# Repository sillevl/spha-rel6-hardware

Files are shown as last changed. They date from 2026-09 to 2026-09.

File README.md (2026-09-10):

# Six-channel relay module

SPHA six-channel relay/light-output module.

## Design files

- `relay-module-light.kicad_pro` — KiCad project
- `relay-module-light.kicad_sch` — top-level schematic
- `relay-module-light.kicad_pcb` — PCB layout
- Additional `.kicad_sch` files — hierarchical schematic sheets
- `models/` — project-specific 3D and mechanical models

## Working with the project

Open the `.kicad_pro` file in KiCad. The design includes files originating from an older KiCad workflow; review schematic links, footprints, design rules, zones, and manufacturing outputs after any conversion or upgrade.

KiCad source files and project-specific libraries are the source of truth. Generated BOM, Gerber, assembly, and fabrication-house outputs are excluded from the repository; regenerate and verify them before manufacturing.

## Repository notes

Temporary KiCad state, locks, autosaves, and backup directories are excluded by `.gitignore`. Board revision, tested KiCad version, manufacturing revision, and hardware/firmware compatibility still need to be recorded when provenance is confirmed.

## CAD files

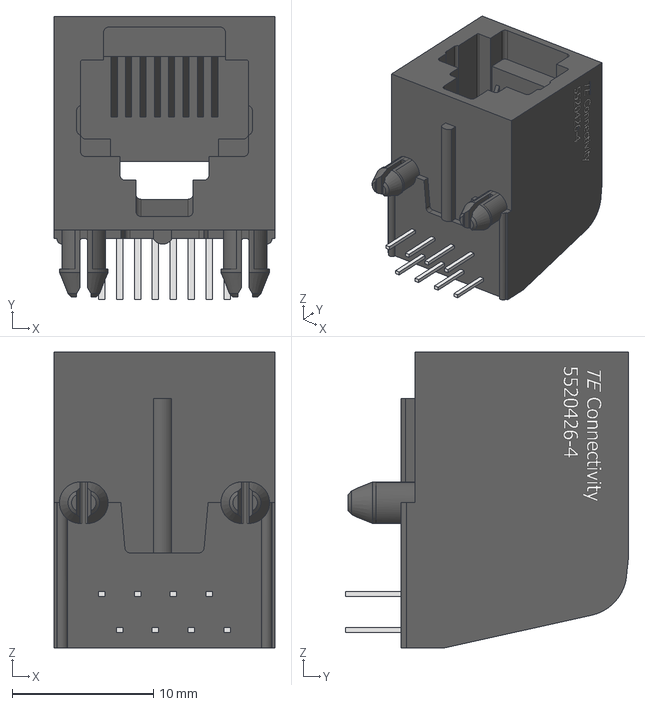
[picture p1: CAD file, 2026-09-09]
models/TE_Connectivity_-_5520426-4.step
15.6 x 20.1 x 21.0 mm
c-5520426-4-a-3d
sdfsdfsdfsdfsdfsdfsdf x 8

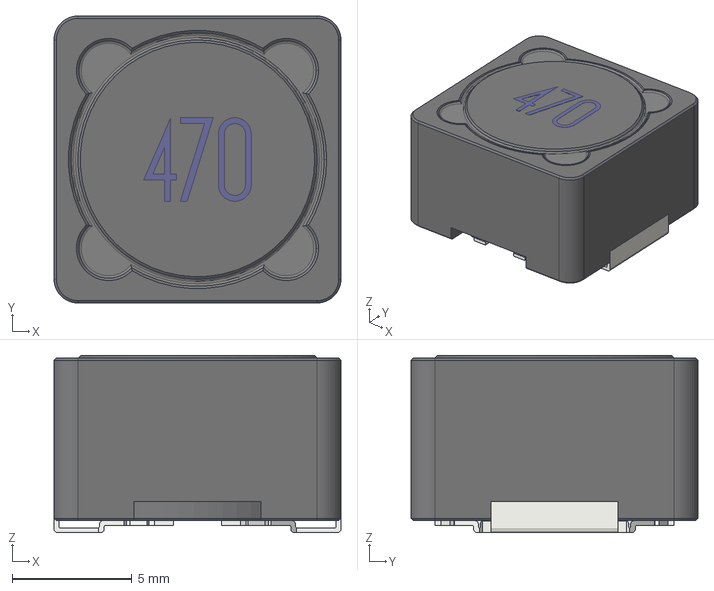
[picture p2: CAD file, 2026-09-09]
models/CDRH127_470M.step
12.0 x 12.0 x 7.41 mm

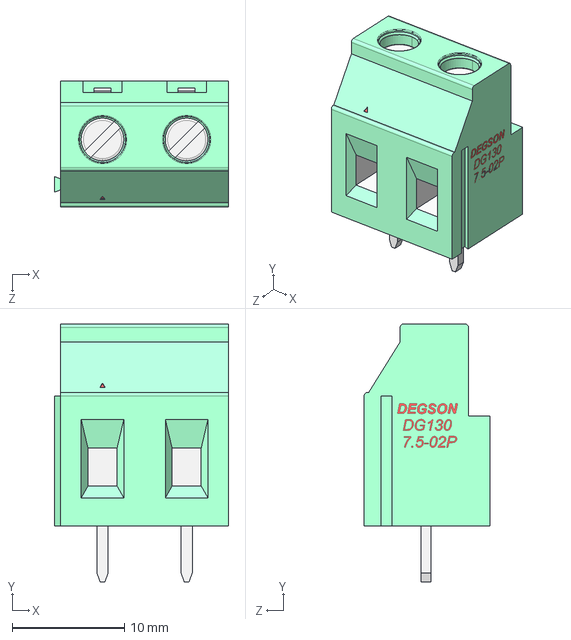
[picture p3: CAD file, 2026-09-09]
models/DG130-7.5-02P-14-00AH.STEP
15.6 x 23.0 x 11.2 mm

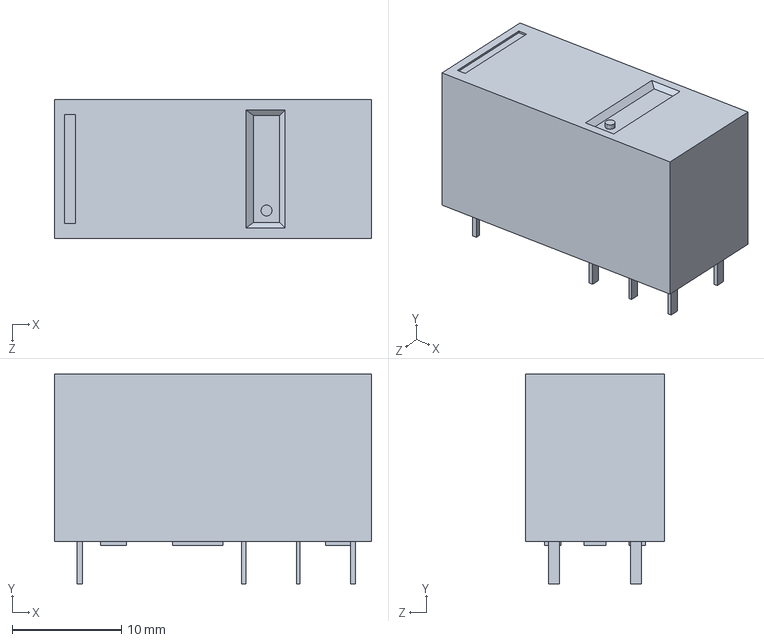
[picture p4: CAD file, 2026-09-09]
models/G5RL_1_E_HR.step
29.0 x 19.2 x 12.7 mm

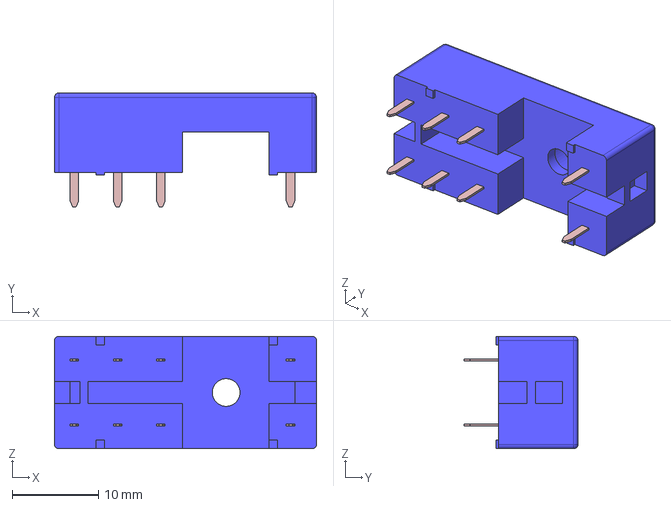
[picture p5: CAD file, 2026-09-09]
models/95152.stp
30.3 x 13.2 x 13.0 mm

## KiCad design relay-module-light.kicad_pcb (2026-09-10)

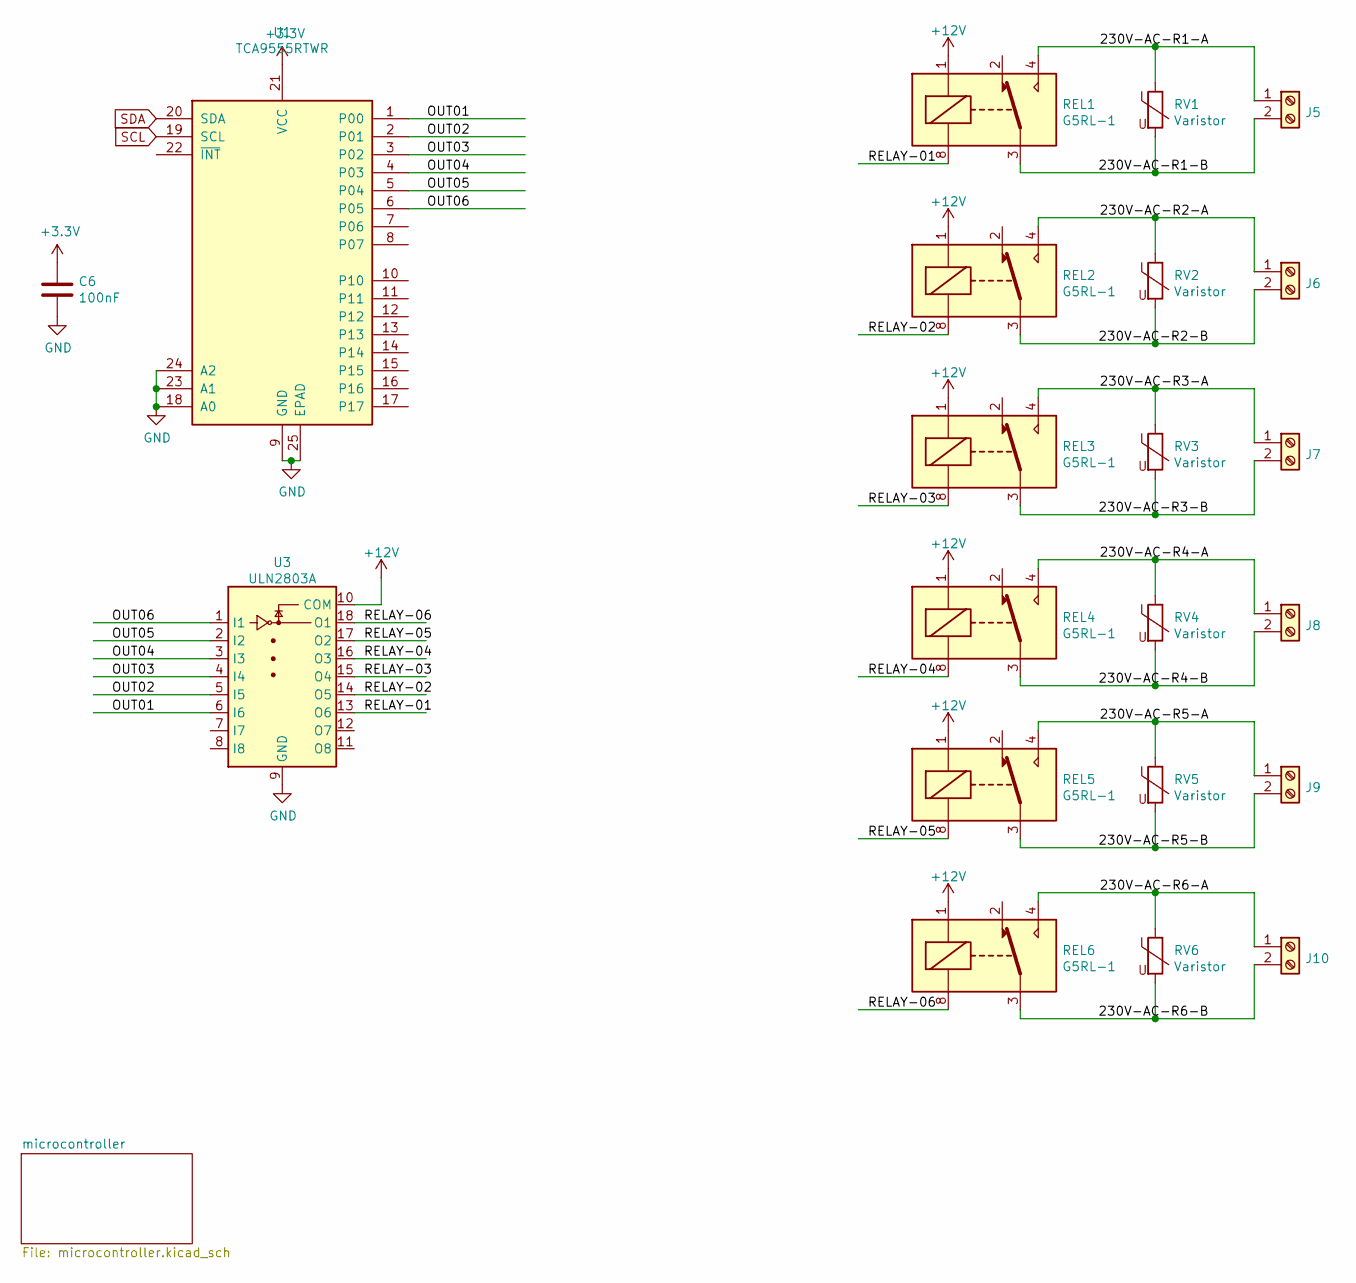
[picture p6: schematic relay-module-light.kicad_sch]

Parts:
C6: 100nF; C_0603_1608Metric_Pad1.05x0.95mm_HandSolder
J5, J6, J7, J8, J9, J10: Screw_Terminal_01x02; TerminalBlock_MetzConnect_Type175_RT02702HBLC_1x02_P7.50mm_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
REL1, REL2, REL3, REL4, REL5, REL6: G5RL-1; Relay_DPDT_Omron_G2RL
RV1, RV2, RV3, RV4, RV5, RV6: Varistor; RV_Disc_D7mm_W4mm_P5mm
U1: TCA9555RTWR; WQFN-24-1EP_4x4mm_P0.5mm_EP2.45x2.45mm
U3: ULN2803A; SOP-18_7x12.5mm_P1.27mm

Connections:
+3V3: C6.1, U1.21 (VCC); also elsewhere on the board
+12V: REL1.1, REL2.1, REL3.1, REL4.1, REL5.1, REL6.1, U3.10 (COM); also elsewhere on the board
/230V-AC-R1-A: J5.1, REL1.4, REL1.5, RV1.1
/230V-AC-R1-B: J5.2, REL1.3, REL1.6, RV1.2
/230V-AC-R2-A: J6.1, REL2.4, REL2.5, RV2.1
/230V-AC-R2-B: J6.2, REL2.3, REL2.6, RV2.2
/230V-AC-R3-A: J7.1, REL3.4, REL3.5, RV3.1
/230V-AC-R3-B: J7.2, REL3.3, REL3.6, RV3.2
/230V-AC-R4-A: J8.1, REL4.4, REL4.5, RV4.1
/230V-AC-R4-B: J8.2, REL4.3, REL4.6, RV4.2
/230V-AC-R5-A: J9.1, REL5.4, REL5.5, RV5.1
/230V-AC-R5-B: J9.2, REL5.3, REL5.6, RV5.2
/230V-AC-R6-A: J10.1, REL6.4, REL6.5, RV6.1
/230V-AC-R6-B: J10.2, REL6.3, REL6.6, RV6.2
/OUT01: U1.1 (P00), U3.6 (I6)
/OUT02: U1.2 (P01), U3.5 (I5)
/OUT03: U1.3 (P02), U3.4 (I4)
/OUT04: U1.4 (P03), U3.3 (I3)
/OUT05: U1.5 (P04), U3.2 (I2)
/OUT06: U1.6 (P05), U3.1 (I1)
/RELAY-01: REL1.8, U3.13 (O6)
/RELAY-02: REL2.8, U3.14 (O5)
/RELAY-03: REL3.8, U3.15 (O4)
/RELAY-04: REL4.8, U3.16 (O3)
/RELAY-05: REL5.8, U3.17 (O2)
/RELAY-06: REL6.8, U3.18 (O1)
unnamed: REL1.2, REL1.7
unnamed: REL2.2, REL2.7
unnamed: REL3.2, REL3.7
unnamed: REL4.2, REL4.7
unnamed: REL5.2, REL5.7
unnamed: REL6.2, REL6.7
SCL: U1.19 (SCL); also elsewhere on the board
SDA: U1.20 (SDA); also elsewhere on the board

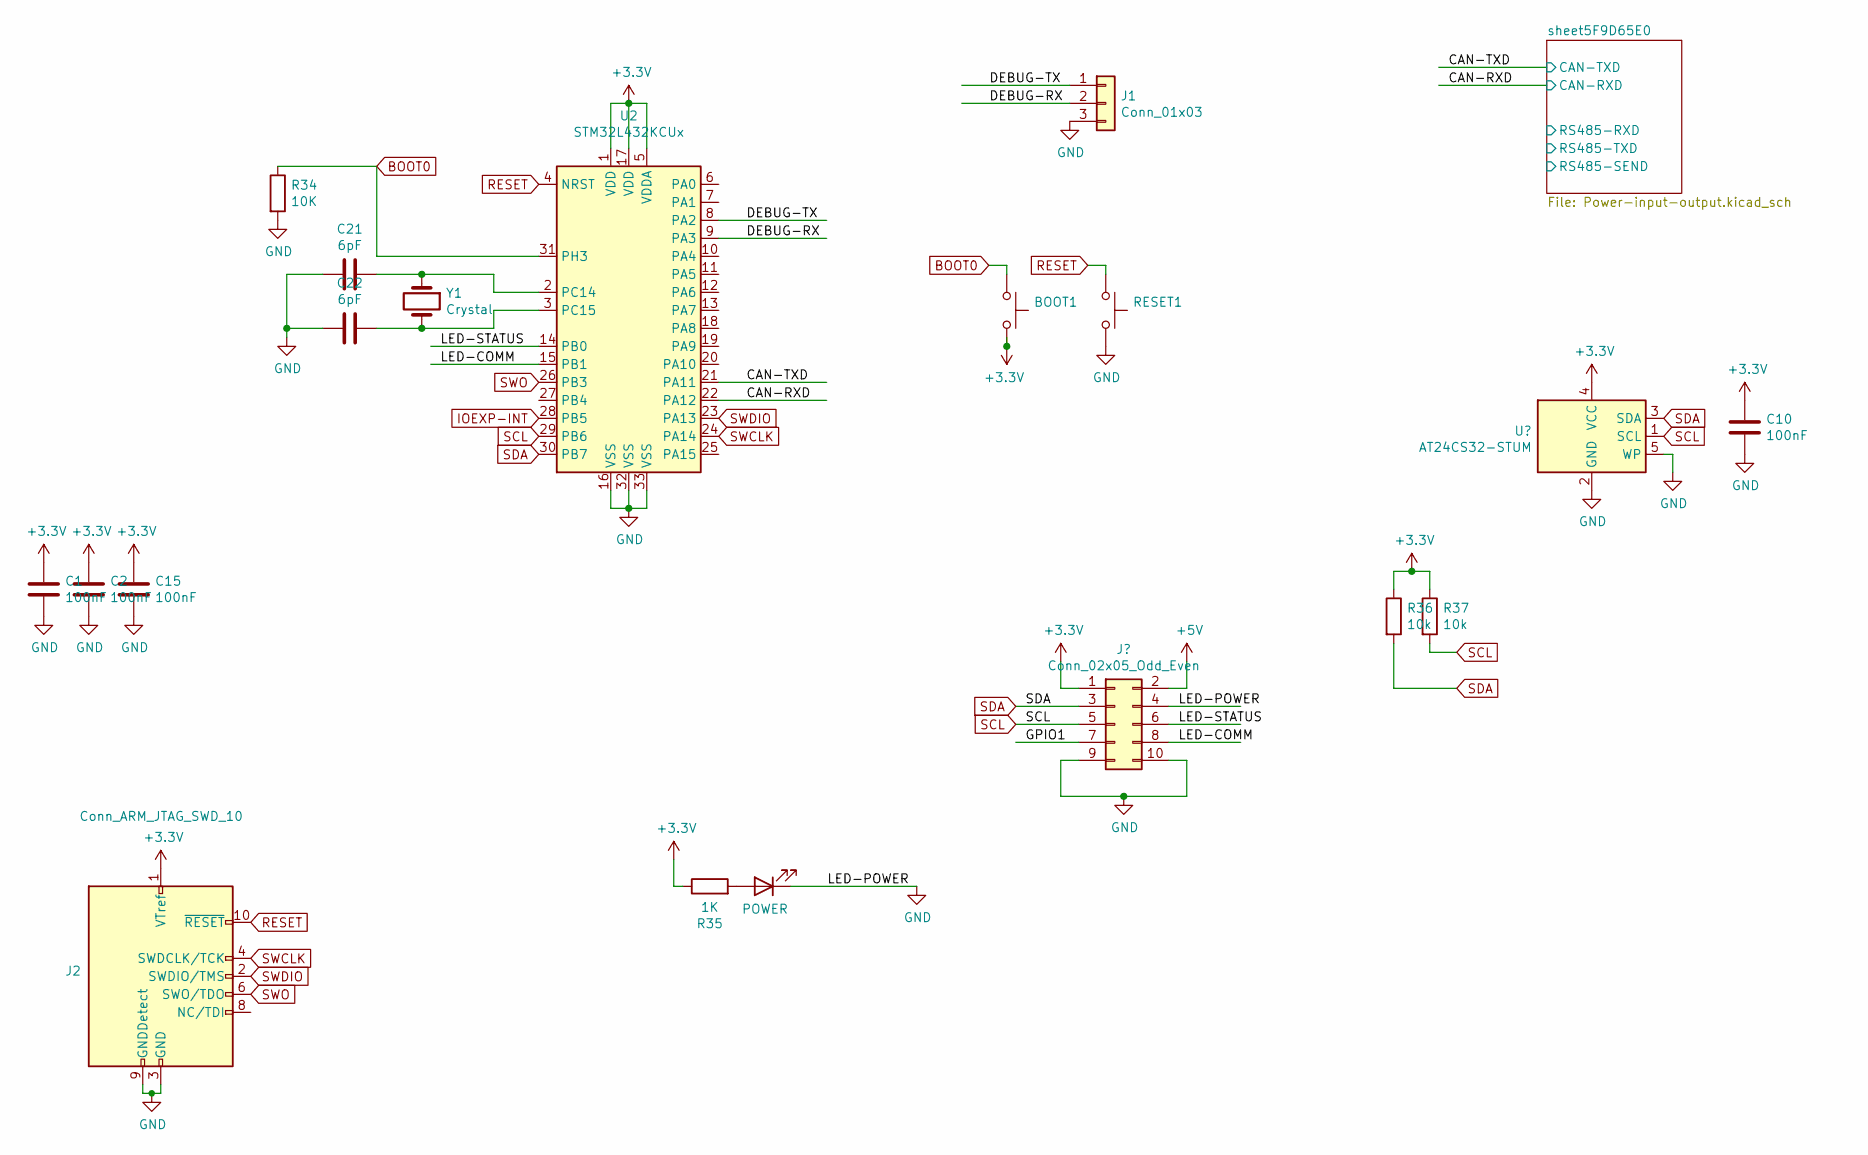
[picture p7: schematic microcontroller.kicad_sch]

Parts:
BOOT1: BOOT0; SW_SPST_B3U-1000P
C1, C2, C10, C15: 100nF; C_0603_1608Metric_Pad1.05x0.95mm_HandSolder
C21, C22: 6pF; C_0603_1608Metric_Pad1.05x0.95mm_HandSolder
J1: Conn_01x03; PinHeader_1x03_P2.54mm_Vertical
J2: Conn_ARM_JTAG_SWD_10; PinHeader_2x05_P1.27mm_Vertical_SMD
LED1: POWER; LED_0603_1608Metric_Pad1.05x0.95mm_HandSolder
R34: 10K; C_0603_1608Metric_Pad1.05x0.95mm_HandSolder
R35: 1K; C_0603_1608Metric_Pad1.05x0.95mm_HandSolder
R36, R37: 10k; C_0603_1608Metric_Pad1.05x0.95mm_HandSolder
RESET1: RESET; SW_SPST_B3U-1000P
U2: STM32L432KCUx; QFN-32-1EP_5x5mm_P0.5mm_EP3.45x3.45mm
Y1: Crystal; Crystal_SMD_MicroCrystal_CC7V-T1A-2Pin_3.2x1.5mm

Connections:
+3V3: BOOT1.2, C1.1, C2.1, C10.1, C15.1, J2.1 (VTref), R35.1, R36.1, R37.1, U2.1 (VDD), U2.5 (VDDA), U2.17 (VDD); also elsewhere on the board
/microcontroller/CAN-RXD: U2.22 (PA12); also elsewhere on the board
/microcontroller/CAN-TXD: U2.21 (PA11); also elsewhere on the board
/microcontroller/DEBUG-RX: J1.2, U2.9 (PA3)
/microcontroller/DEBUG-TX: J1.1, U2.8 (PA2)
/microcontroller/LED-COMM: U2.15 (PB1); also elsewhere on the board
/microcontroller/LED-STATUS: U2.14 (PB0); also elsewhere on the board
BOOT0: BOOT1.1, R34.1, U2.31 (PH3)
unnamed: C21.1, U2.2 (PC14), Y1.1
unnamed: C22.1, U2.3 (PC15), Y1.2
unnamed: LED1.2 (A), R35.2
RESET: J2.10 (~RESET~), RESET1.1, U2.4 (NRST)
SCL: R37.2, U2.29 (PB6); also elsewhere on the board
SDA: R36.2, U2.30 (PB7); also elsewhere on the board
SWCLK: J2.4 (SWDCLK/TCK), U2.24 (PA14)
SWDIO: J2.2 (SWDIO/TMS), U2.23 (PA13)
SWO: J2.6 (SWO/TDO), U2.26 (PB3)

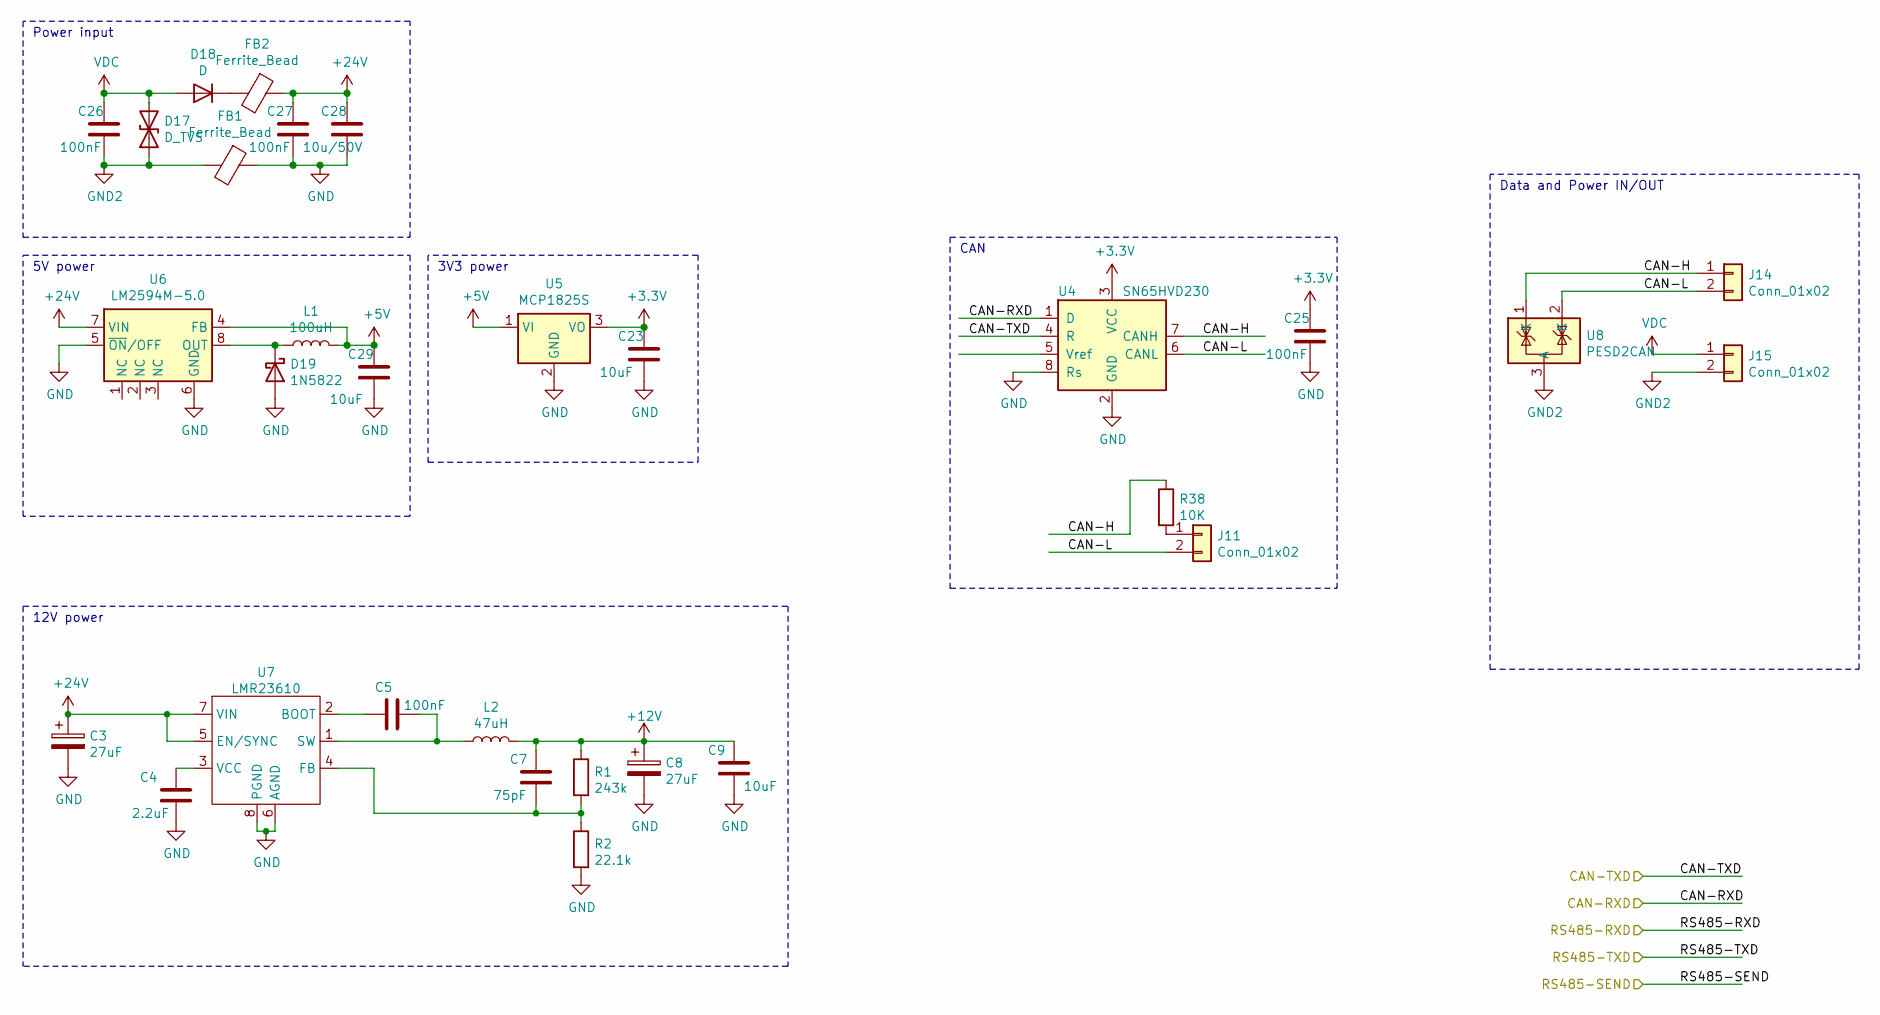
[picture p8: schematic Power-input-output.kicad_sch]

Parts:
C3, C8: 27uF; CP_Elec_6.3x5.7
C4: 2.2uF; C_0603_1608Metric
C5, C25, C26, C27: 100nF; C_0603_1608Metric
C7: 75pF; C_0603_1608Metric
C9, C23, C29: 10uF; C_1206_3216Metric
C28: 10u/50V; C_1206_3216Metric
D17: D_TVS; D_SMB
D18: D; D_SMA
D19: 1N5822; D_SOD-123
FB1, FB2: Ferrite_Bead; R_0603_1608Metric
J11: Conn_01x02; PinHeader_1x02_P2.54mm_Vertical
J14, J15: Conn_01x02; TerminalBlock_bornier-2_P5.08mm
L1: 100uH; L_Wuerth_WE-PD2-Typ-MS
L2: 47uH; L_12x12mm_H8mm
R1: 243k; R_0603_1608Metric
R2: 22.1k; R_0603_1608Metric
R38: 10K; R_0603_1608Metric
U4: SN65HVD230; SOIC-8_3.9x4.9mm_P1.27mm
U5: MCP1825S; SOT-223
U6: LM2594M-5.0; SOIC-8_3.9x4.9mm_P1.27mm
U7: LMR23610; HSOIC-8
U8: PESD2CAN; SOT-23

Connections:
+3V3: C23.1, C25.1, U4.3 (VCC), U5.3 (VO); also elsewhere on the board
+5V: C29.1, L1.2, U5.1 (VI), U6.4 (FB); also elsewhere on the board
+12V: C7.2, C8.1, C9.1, L2.2, R1.1; also elsewhere on the board
+24V: C3.1, C27.1, C28.1, FB2.1, U6.7 (VIN), U7.5 (EN/SYNC), U7.7 (VIN)
/microcontroller/CAN-RXD: U4.1 (D); also elsewhere on the board
/microcontroller/CAN-TXD: U4.4 (R); also elsewhere on the board
/microcontroller/sheet5F9D65E0/CAN-H: J14.1, R38.1, U4.7 (CANH), U8.1 (K)
/microcontroller/sheet5F9D65E0/CAN-L: J11.2, J14.2, U4.6 (CANL), U8.2 (K)
GND2: C26.2, D17.1 (A1), FB1.2, J15.2, U8.3 (A)
unnamed: C4.1, U7.3 (VCC)
unnamed: C5.1, U7.2 (BOOT)
unnamed: C5.2, L2.1, U7.1 (SW)
unnamed: C7.1, R1.2, R2.1, U7.4 (FB)
unnamed: D18.1 (K), FB2.2
unnamed: D19.1 (K), L1.1, U6.8 (OUT)
unnamed: J11.1, R38.2
VDC: C26.1, D17.2 (A2), D18.2 (A), J15.1

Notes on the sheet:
12V power
3V3 power
CAN
5V power
Data and Power IN/OUT
Power input

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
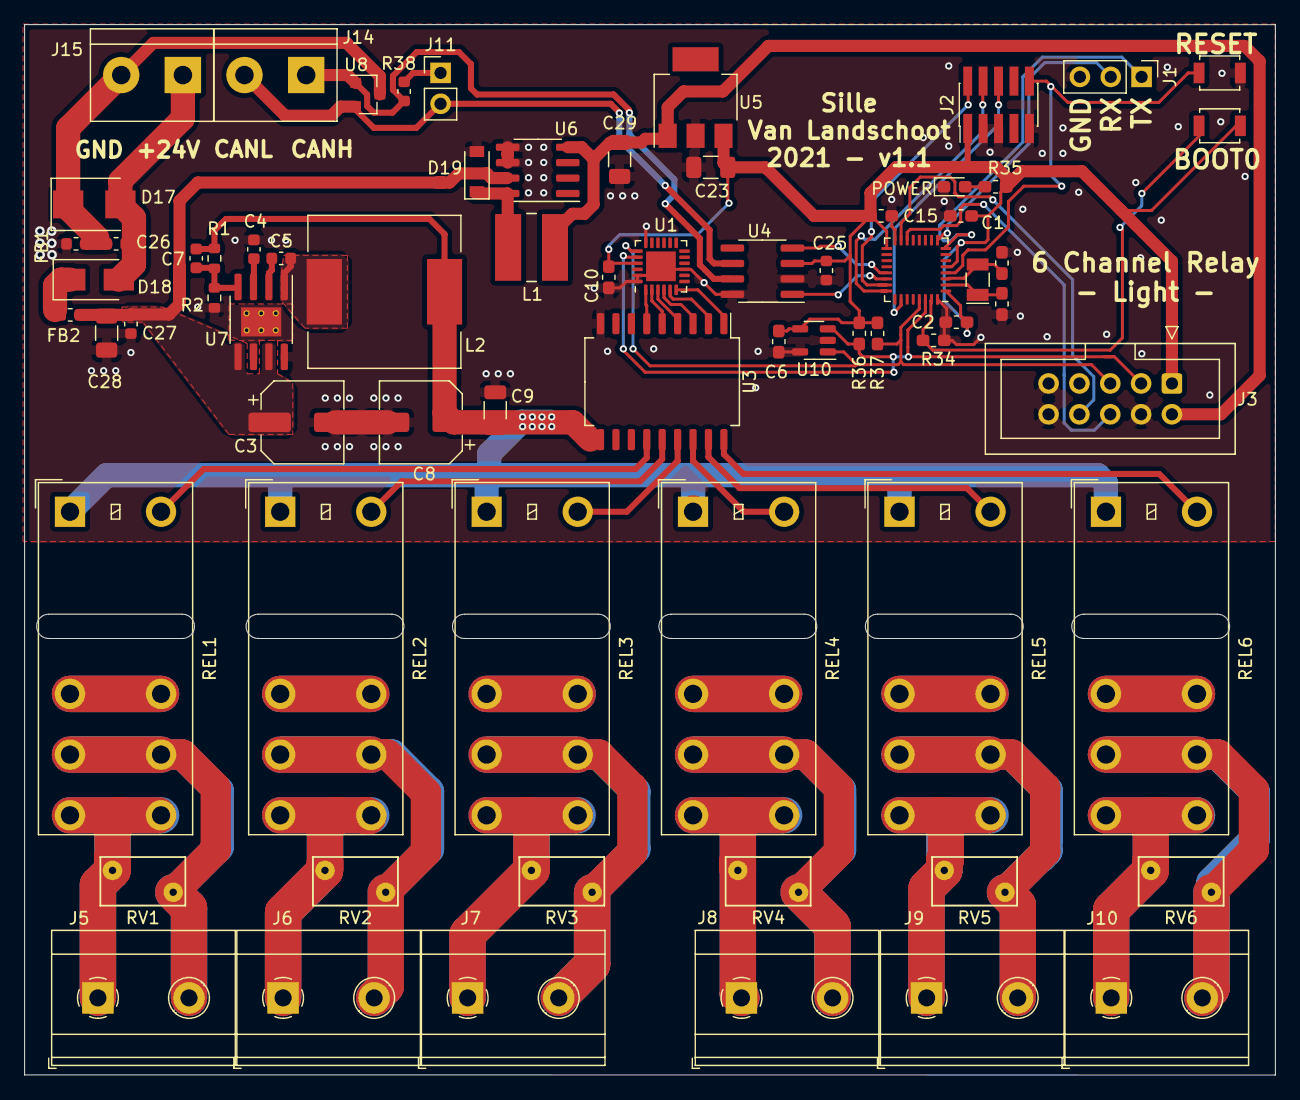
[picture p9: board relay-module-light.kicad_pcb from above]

Board: 2 copper layers, 103.0 x 86.5 mm, 70 parts (0 on the bottom side), 62 nets.

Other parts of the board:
J3: Conn_02x05_Odd_Even; IDC-Header_2x05_P2.54mm_Vertical
U10: AT24CS32-STUM; SOT-23-5

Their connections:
+3V3: J3.1, U10.4 (VCC); also elsewhere on the board
+5V: J3.2; also elsewhere on the board
/microcontroller/LED-COMM: J3.8; also elsewhere on the board
/microcontroller/LED-STATUS: J3.6; also elsewhere on the board
SCL: J3.5, U10.1 (SCL); also elsewhere on the board
SDA: J3.3, U10.3 (SDA); also elsewhere on the board

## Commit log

2026-09-09 Preserve hardware project sources
    [95152.stp, CDRH127_470M.step, DG130-7.5-02P-14-00AH.STEP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]
2026-09-09 Upgrade KiCad design files to 10.0.6
    [Power-input-output.kicad_sch, microcontroller.kicad_sch, relay-module-light.kicad_pcb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]
2026-09-10 Standardize KiCad asset directories
    [95152.stp, CDRH127_470M.step, DG130-7.5-02P-14-00AH.STEP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]
